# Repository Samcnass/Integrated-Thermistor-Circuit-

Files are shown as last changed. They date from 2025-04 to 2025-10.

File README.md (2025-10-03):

# Integrated Thermistor Circuit-
Class/Personal project for an analog integrated thermistor circuit that measures temperature using a simple comparison system with visual feedback using LEDs and console output. 

## Project Overview 

The circuit continuously reads:
- A desired temperature, set using a 10kΩ dial potentiometer
- The room's (or object if attached) temperature with a 10kΩ thermistor (Calibrated using thermometer data)

The system compares the two temperatures and will light up:
- Red LED: if it is too hot
- Blue LED: if it is too cold
- Green LED: if it is just right (within range set in code)

This project is great because it blends analog components, component calibration, and simple boolean logic using an Arduino. It is also easily expandable to other projects. 

A full schematic, PCB design, and Arduino IDE code are available via included folders. 

## Components required for project

| Component | Quantity |
|---|---|
| Arduino Uno or Nano | 1 |
| 10kΩ Analog Thermistor | 1 |
| 10kΩ Dial Potentiometer | 1 |
| 10kΩ Resistor | 1 |
| 330Ω Resistors | 3 |
| LEDs (Red, Green, Blue) | 3 |
| Breadboard + Jumper Wires | as needed |

## Circuit Description 

- The thermistor forms a voltage divider with a 10kΩ resistor, which is then connected to an analog pin to read temperature
- A dial potentiometer is used to set a desired temperature range from the user 
- The Arduino will compare the thermistor and potentiometer readings and will light up an LED to indicate:
  - **Too cold**: Thermistor reading below lower threshold
  - **Too hot**: Thermistor reading above upper threshold
  - **Just right**: Reading within user-defined range

## Circuit Schematic 

full schematic available in /schematic/ folder. 
This can be opened in KiCAD for viewing.
You can also view the schematic pdf in said folder for easy viewing.
The schematic was done outside of class and was part of a personal project. 

## PCB
Full PCB file is available in /PCB/ folder. 
This can be opened in KiCAD for viewing.
You can also view the PCB png for easy viewing.
The PCB was designed as part of a personal project.

## Arduino IDE Code 

Arduino code to read and compare values is found in the /Code/ folder.
The code includes:
- variable to set desired range (ex: range=3, temperature range is plus or minus 3 away from desired temperature)
- Analog to voltage conversion function for easy reading
- LED boolean logic
- Analog inputs from thermistor and potentiometer
- Calibrated thermistor function to convert voltage to temperature (change depending on thermistor)
- Console output depending on temperature comparison

## Calibration 
The thermistor was calibrated using temperature data from a thermometer.  
There is a Microsoft Excel file located in the /Documents/ folder as well as a png of the calibration plot. 
You may change your thermistor calibration as you see fit

---

## Images
An image of the real-world circuit is in the /Images/ folder. The image is of an Arduino Uno but can be changed with an Arduino Nano if needed. 

## How to use 
1. Wire the circuit according to the schematic
2. Change desired temperature range within code 
3. Upload the code to your board
4. Turn the dial to set your desired temperature 
5. Observe LEDs and Arduino console for live output

## Future Improvements
- Add OLED display for real-time temperature readout instead of using console
- Implement circuit onto a complete PCB board and implement in thermodynamics experiements
  
## License
This project is open-source under the LICENSE

-- 

## Other project uses
I have used this circuit to measure the temperature of a refrigerator to study its heating/cooling processes as well as its coefficient of performance.

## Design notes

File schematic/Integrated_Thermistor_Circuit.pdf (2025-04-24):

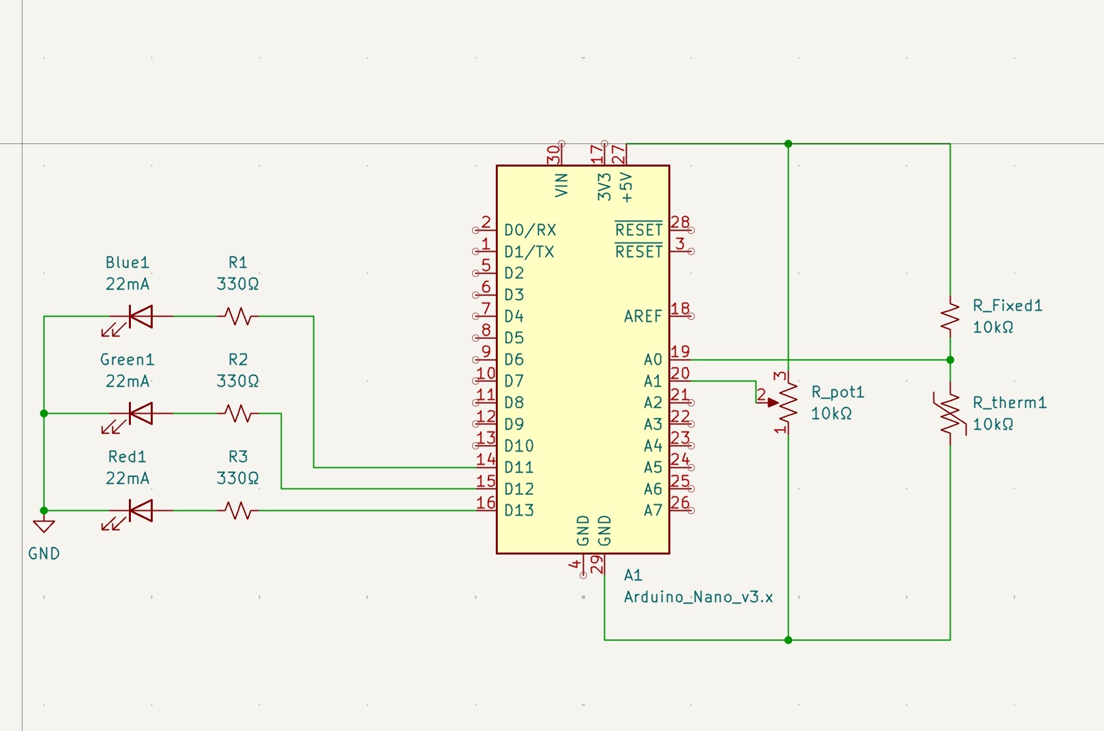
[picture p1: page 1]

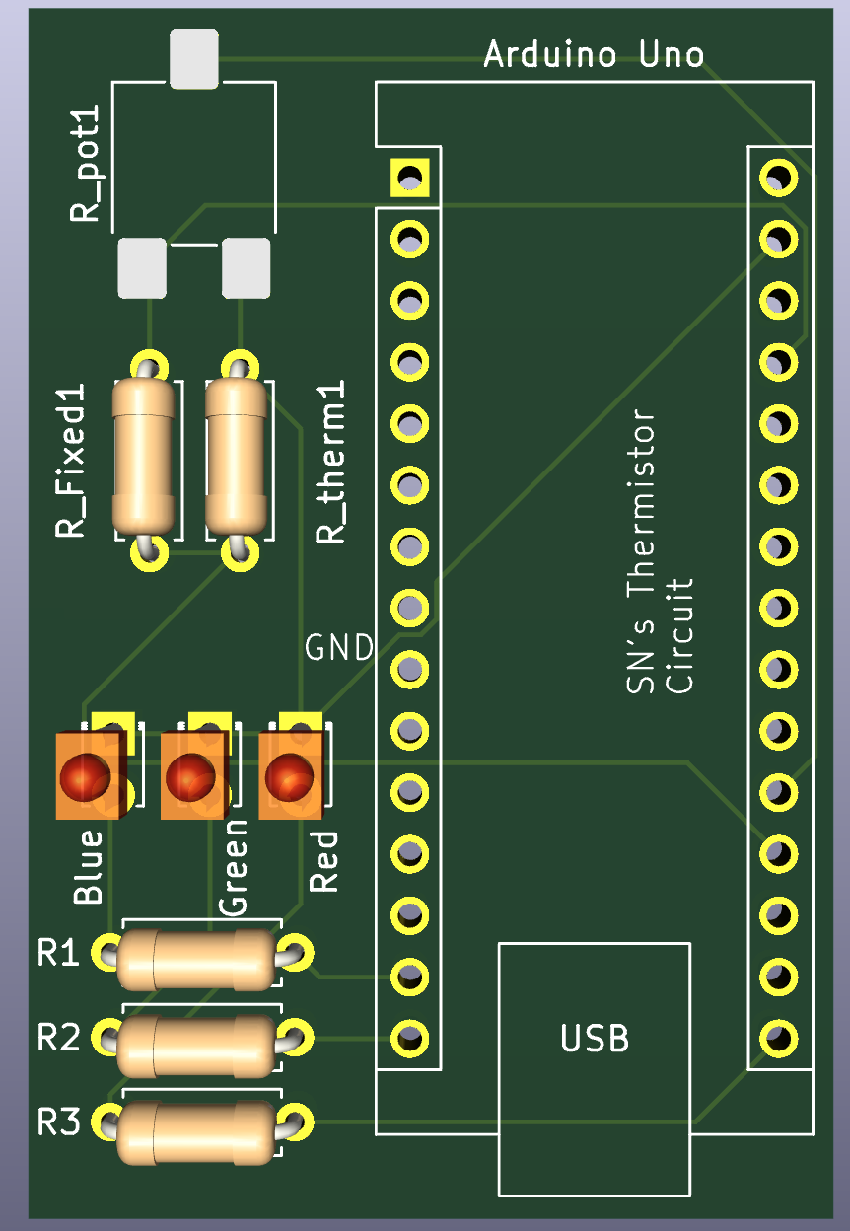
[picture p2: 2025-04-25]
PCB/Thermistor_PCB.png

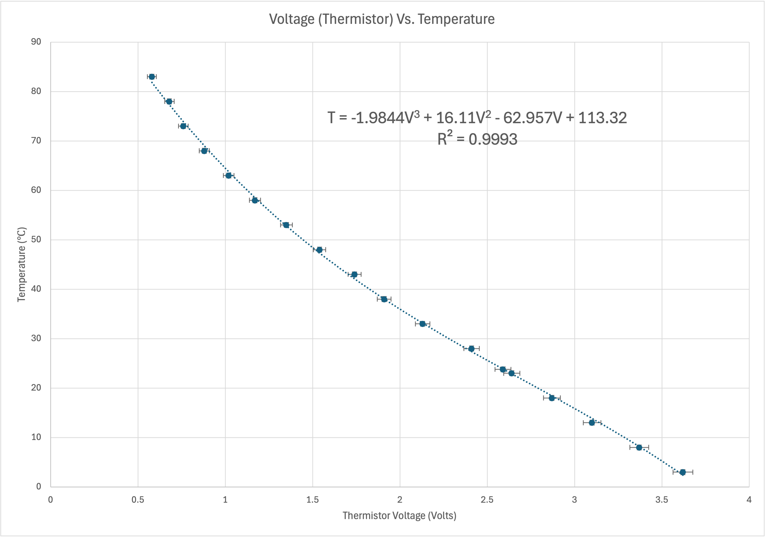
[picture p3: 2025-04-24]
Documents/TempVSVoltage.png

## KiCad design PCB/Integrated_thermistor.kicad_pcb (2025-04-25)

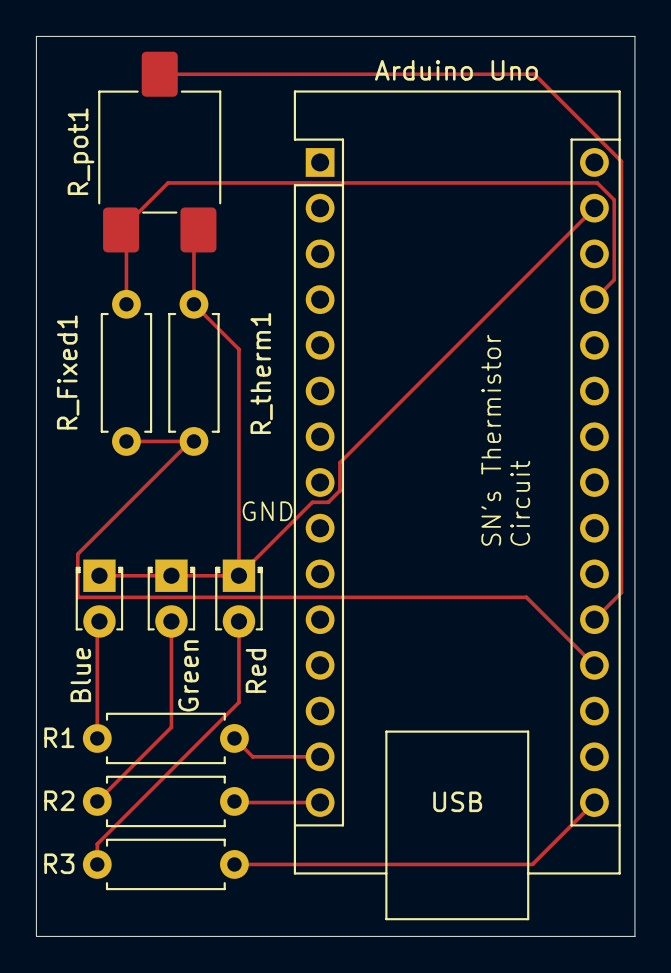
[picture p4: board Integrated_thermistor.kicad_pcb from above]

Board: 2 copper layers, 33.2 x 50.0 mm, 10 parts (0 on the bottom side), 10 nets.

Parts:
Arduino Uno: Arduino_Nano_v3.x; Arduino_Nano
Blue: 22mA; LED_D1.8mm_W3.3mm_H2.4mm
Green: 22mA; LED_D1.8mm_W3.3mm_H2.4mm
R1, R2, R3: 330Ω; R_Axial_DIN0207_L6.3mm_D2.5mm_P7.62mm_Horizontal
R_Fixed1: 10kΩ; R_Axial_DIN0207_L6.3mm_D2.5mm_P7.62mm_Horizontal
R_pot1: 10kΩ; Potentiometer_ACP_CA6-VSMD_Vertical
R_therm1: 10kΩ; R_Axial_DIN0207_L6.3mm_D2.5mm_P7.62mm_Horizontal
Red: 22mA; LED_D1.8mm_W3.3mm_H2.4mm

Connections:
unnamed: Arduino Uno.27 (+5V), R_Fixed1.1, R_pot1.3
unnamed: Arduino Uno.19 (A0), R_Fixed1.2, R_therm1.1
unnamed: Arduino Uno.20 (A1), R_pot1.2
unnamed: Arduino Uno.14 (D11), R1.2
unnamed: Arduino Uno.15 (D12), R2.2
unnamed: Arduino Uno.16 (D13), R3.2
unnamed: Blue.2 (A), R1.1
unnamed: Arduino Uno.29 (GND), Blue.1 (K), Green.1 (K), R_pot1.1, R_therm1.2, Red.1 (K)
unnamed: Green.2 (A), R2.1
unnamed: R3.1, Red.2 (A)

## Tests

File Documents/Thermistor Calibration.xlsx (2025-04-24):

Temp (℃) | Temp unc. (℃) | Vth (V) | Vth unc. (V) | Vr (V) | Vr unc. (V) | I (A) | I unc. (A) | Rth Room Temp (Ω) | uncertainty
23.8 | 0.5 | 2.59 | 0.05 | 2.41 | 0.12 | 0.0002426988922 | 1.507290814e-05 | 10.44 | 0.1244
3 | 0.5 | 3.62 | 0.06 | 1.38 | 0.13 | 0.0001389728097 | 1.465654141e-05
8 | 0.5 | 3.37 | 0.05 | 1.63 | 0.12 | 0.0001641490433 | 1.47576013e-05 | Source Voltage (V)
13 | 0.5 | 3.1 | 0.05 | 1.9 | 0.12 | 0.0001913393756 | 1.486674597e-05 | 5 | 0.07
18 | 0.5 | 2.87 | 0.05 | 2.13 | 0.12 | 0.0002145015106 | 1.495972107e-05
23 | 0.5 | 2.64 | 0.05 | 2.36 | 0.12 | 0.0002376636455 | 1.505269616e-05 | R2 Room Temp (Ω)
28 | 0.5 | 2.41 | 0.04 | 2.59 | 0.11 | 0.0002608257805 | 1.514567126e-05 | 9.93 | 0.14
33 | 0.5 | 2.13 | 0.04 | 2.87 | 0.11 | 0.0002890231621 | 1.525885833e-05
38 | 0.5 | 1.91 | 0.04 | 3.09 | 0.11 | 0.0003111782477 | 1.534779103e-05
43 | 0.5 | 1.74 | 0.04 | 3.26 | 0.11 | 0.0003282980866 | 1.541651176e-05
48 | 0.5 | 1.54 | 0.04 | 3.46 | 0.11 | 0.0003484390735 | 1.549735966e-05
53 | 0.5 | 1.35 | 0.03 | 3.65 | 0.10 | 0.0003675730111 | 1.557416518e-05
58 | 0.5 | 1.17 | 0.03 | 3.83 | 0.10 | 0.0003856998993 | 1.56469283e-05
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

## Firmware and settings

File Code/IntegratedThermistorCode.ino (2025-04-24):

const int temperaturePin = A0; //read from thermistor 
const int potentPin = A1; //read from potentiometer
const int redPin = 13; //set LED pins 
const int greenPin = 12;
const int bluePin = 11;

void setup()
{
  //initialize LED pins
    pinMode(redPin, OUTPUT);
    pinMode(greenPin, OUTPUT);
    pinMode(bluePin, OUTPUT);
    Serial.begin(9600); //Initialize serial port 
}

void loop()
{

  //Declare variables 
    float voltage, degreesC, degreesF, potentvoltage, setdegreesC, setdegreesF, tempdiff, desiredtemp; 
    
    desiredtemp = 3; //input max temperature difference between thermistor and potentiometer 
    voltage = getVoltage(temperaturePin); //Measure the voltage at the analog 0 pin
    potentvoltage = getVoltage(potentPin); //Measure the voltage at the analog 1 pin, gives desired temperature from potentiometer 

    degreesC = (-1.9844*pow(voltage,3))+(16.11*pow(voltage,2))-(62.957*voltage)+113.32-2; // Convert the voltage to degrees Celsius using calibrated thermistor data 
    //Note: Thermometer used to calibrate thermistor reads about 2 degrees higher than the rest, the thermistor temperature is subtracted by an arbitrary 2 to account for the shift

    setdegreesC = (-1.9844*pow(potentvoltage,3))+(16.11*pow(potentvoltage,2))-(62.957*potentvoltage)+113.32-2; //convert potentiometer voltage to degrees Celsius with calibrated data
  //Convert degrees Celsius to Fahrenheit
    degreesF = degreesC * (9.0 / 5.0) + 32.0; 
    setdegreesF = setdegreesC * (9/5)+32;

    tempdiff = degreesC - setdegreesC; //difference between desired and measured temperature 

  //check if measured temp is within desired range. Light different LEDs depending on desired temperature difference 
    if(tempdiff<-desiredtemp) //if temp too low
    {
      digitalWrite(bluePin, HIGH);
      digitalWrite(redPin,LOW);
      digitalWrite(greenPin,LOW);
      Serial.print("Status:  Temperature exceeds allowed range and is too cold  ");
    }
    else if(tempdiff>=-desiredtemp && tempdiff <= desiredtemp) //if temp in desired range 
    {
      digitalWrite(greenPin,HIGH);
      digitalWrite(redPin,LOW);
      digitalWrite(bluePin,LOW);
      Serial.print("Status:  Temperature in range  ");
    }
    else //if temp too high
    {
      digitalWrite(redPin,HIGH);
      digitalWrite(bluePin,LOW);
      digitalWrite(greenPin,LOW);
      Serial.print("Status:  Temperature exceeds allowed range and is too hot  ");
    }
  
  //print results 
    Serial.print("voltage: ");
    Serial.print(voltage);
    Serial.print("  deg C: ");
    Serial.print(degreesC);
    Serial.print("  deg F: ");
    Serial.print(degreesF);
    Serial.print("  Set Voltage:  ");
    Serial.print(potentvoltage);
    Serial.print("  Set Degrees C: ");
    Serial.println(setdegreesC);
    
    delay(3000); // repeat once per second (change as you wish!)
}

float getVoltage(int pin)   //Get voltage from analog pins
{
    return (analogRead(pin) * 0.004882814); //converts analog data to true voltage 
}

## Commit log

2025-04-24 Create schematic_text
2025-04-24 Add schematic KiCAD file and schematic pdf
    [Integrated_thermistor.kicad_sch]
2025-04-24 image of real-world circuit
2025-04-25 Add integrated thermistor pcb file and png
    [Integrated_thermistor.kicad_pcb]
2025-04-25 Add pcb file and png
    [Integrated_thermistor.kicad_pcb]
2025-04-25 Updated PCB
